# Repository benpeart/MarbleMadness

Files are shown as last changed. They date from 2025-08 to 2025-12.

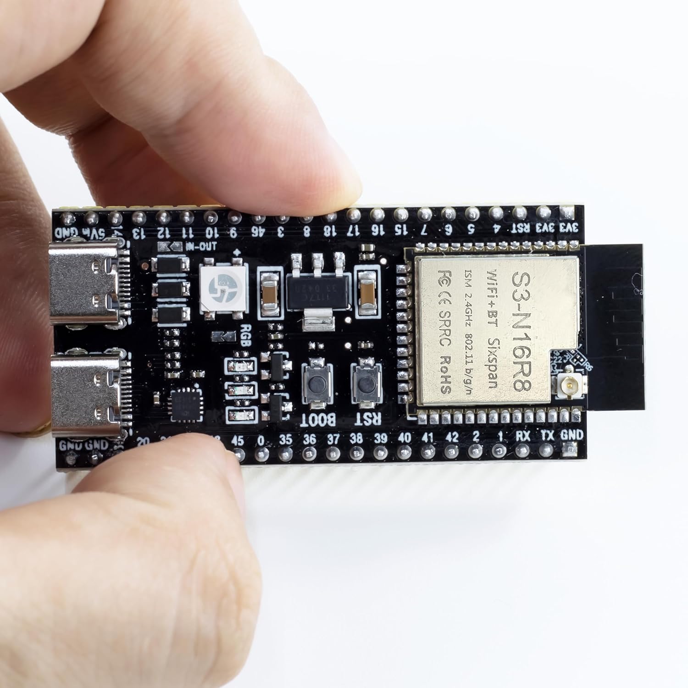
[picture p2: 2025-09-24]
documentation/81TZLf-2A1L._AC_SL1500_.jpg

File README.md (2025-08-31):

# Marble Madness
A Digital Marble Roller maker project.

## Configure WiFi settings

When Marble Madness first boots up, it will attempt to connect to WiFi using the current settings.
If that fails, it will will go into "Access Point mode" which will allow you to access it via WiFi using your laptop or phone.

Connect tothe  Marble Madness WiFi access point with your device and follow the onscreen instructions to configure the WiFi settings.
Marble Madness will then reboot and connect using the updated settings.

Any time Marble Madness cannot connect with the current WiFi settings, it will go into AP mode so that the settings can be updated.
If you are still having problems, reboot Marble Madness (unplug/plug) twice a few seconds apart (less than 10) and the settings will be cleared and it will go into AP mode.

## REST API documentation

Marble Madness connects to the WiFi with the device name "MarbleMadness." The web ui and REST API can be found at http://MarbleMadness/. 
Alternately, check your router for the IP address.

There are four REST endpoints that make up the REST API:

1. "http://MarbleMadness/api/settings"
1. "http://MarbleMadness/api/modes"
1. "http://MarbleMadness/api/faces"

## 'Settings' REST API

A GET sent to the Settings endpoint will return a result that includes the following entries:
PUT will allow you to set some or all of the same values.

```
{
    "mode": "MarbleMadness",
    "brightness": 255,
    "speed": 25,
    "clockFace": "Off",
    "clockColor": "#FFFFFF"
}
```

### Mode

The mode specifies which of the available MarbleMadness modes is currently active. This can vary as more are added or removed but currently the list of available modes includes:

```
{
    "MarbleRoller",
    "xy_test",
    "test",
    "off"
}    
```        

### Brightness

The valid range is 0 (off) to 255 (bright). The default is 255.

### Speed

Speed is a value between 0 (slow) to 255 (fast). The default is 127.
Not all modes can honor all speeds; each one is responsible for making a 'best effort.'

### clockFace

Choose what clock face (if any) is displayed.

```
{
    "Off",
    "Digital",
    "Analog"
}
```

### clockColor

A hexadecimal color is specified with: #RRGGBB, where the RR (red), GG (green) and BB (blue) hexadecimal integers specify the components of the color.

## 'Modes' REST API

A GET sent to the /api/modes endpoint will return an array of the available modes.
PUT will allow you to set some or all of the same values.

A sample result would be the following:

```
["MarbleRoller","xy_test","test"]
```

## 'Faces' REST API

A GET sent to the /api/faces endpoint will return an array of the available clock faces.
PUT will allow you to set some or all of the same values.

A sample result would be the following:

```
["Off","Digital","Analog"]
```

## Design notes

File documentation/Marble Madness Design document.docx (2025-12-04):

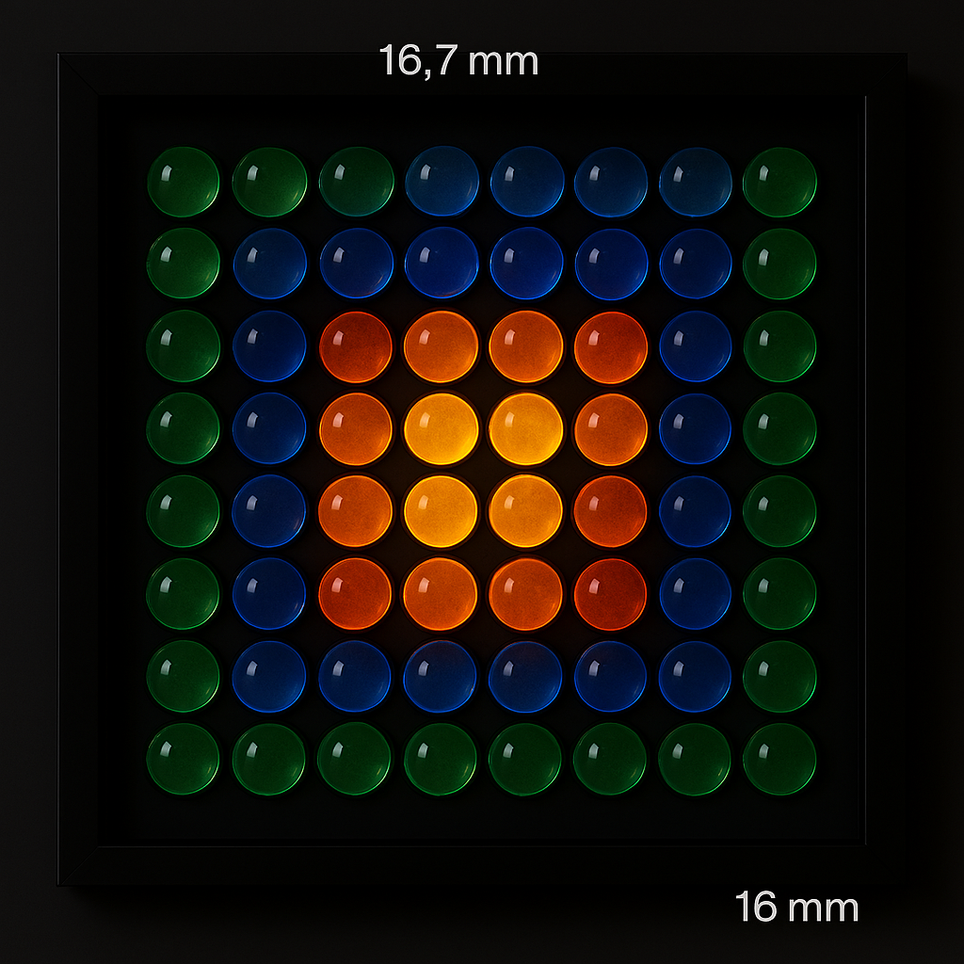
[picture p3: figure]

Here’s a clean layout plan for pairing 16 mm marbles with a 60 LEDs/m WS2812B strip (https://www.amazon.com/dp/B01CDTE9UC?th=1) (≈ 16.67 mm LED pitch) so that each marble gets its own “pixel” without crowding or gaps.

📐 Core Measurements

Element | Size / Spacing
Marble diameter | 16 mm
LED pitch (center-to-center) | 16.67 mm
Recommended hole center spacing | 16.7 mm
Recommended hole diameter | 15.8–16.0 mm

# Hardware Notes

- For reference, the kaleidoscope has 20 x 39 = 780 pixels
- A ‘standard’ marble is ~16mm in diameter
- A 60 LEDs/m WS2812B strip (https://www.amazon.com/dp/B01CDTE9UC?th=1) has a 16.67mm LED pitch
  - Dave’s 3D printer has a print volume of 350 x 350 x 325 mm or 19 x 19 = 361 marbles (leaving room for a margin and frame).

## Power

- usb c pd adjustable power supply?
- DC 4.75-23V to 3.3V Buck Converter Board (https://www.amazon.com/dp/B0B779CGJQ?ref=ppx_yo2ov_dt_b_fed_asin_title&th=1)

# Software Notes

1. Why does checking dirty flag make updates jerky (esp Matrix)
2. Fireworks
3. Googley eyes
4. Water ripple
5. Rainfall
6. Games
  a. Tetris
  b. Tron
  c. Breakout
  d. Frozen bubble game
7. Hourglass?
8. Lava lamp
9. Display static patterns/images
  a. clock that changes every minute
10. Display dynamic patterns/images
  a. Animated gifs, videos, etc
11. Animated transitions
  a. Marbles ‘fall’ from the top down in a random pattern ala connect 4 (need a physics engine (https://github.com/erincatto/box2d)?)
  b. Marbles ‘fall’ out the bottom ala Connect 4
  c. Marbles ‘roll’ down from row to row filling in the picture
    i. Try using every other row to ‘draw’ the track the marbles are rolling down
  d. Standard transitions:
    i. Simple Cut
    ii. Fade to/from black
    iii. Alpha blend to next picture
    iv. Wipe
    v. Push/slide from left/right/top/bottom - old slide out, new slide in

# Done

1. Connect 4 clock
  a. Only have enough perf to animate the marbles needed for the clock
  b. Only need vertical walls around numbers (fewer box2d items to compute)
  c. Only need 1 ‘floor’ below the bottom row of numbers in the middle of the screen
  d. Store which marbles are ‘lit’ in parallel array initialized by drawDigitalClock() in RealTimeClock.cpp
  e. When the minute changes, remove the floor and when all marbles have left the screen, replace floor then move all the marbles (with the new time) above the top of the screen so they can fall into place
2. Conway game of life
3. marble roller (simulated and physics based, with and without physical ‘tracks’)
  a. Try alpha blending between marbles in motion (ala Matrix/Kaleidoscope) to give a better sense of motion. Look at “lerp” (ask AI). Or let them dim ala ‘Matrix.’
4. ‘Ringer’ game - marbles in center, one is ‘shot’ from side, hits marbles, they scatter
5. “Bounce” where marbles drop to the bottom of the display with random direction and speed
6. “Pachinko” simulate the marbles and pins of the Pachinko game
7. “Fire” and “Matrix” – exactly what you think…

# Conway Life Pattern Information

There are excellent online libraries that collect Conway’s Game of Life patterns in RLE format, complete with descriptions and classifications.

🌐 Recommended Sites

- Life Pattern Library (life.angen.ai) A massive curated collection of over 1,700 patterns, organized into categories like oscillators, still lifes, spaceships, methuselahs, guns, and more. Each entry includes the RLE code, description, discoverer, and year life.angen.ai (https://life.angen.ai/patterns). 👉 Explore the Life Pattern Library (https://life.angen.ai/patterns)
- ConwayLife Pattern Library (conwaylife.appspot.com) Hosted by the ConwayLife community, this site provides a searchable library of RLE files, with links to LifeWiki pages for detailed explanations. You’ll find everything from simple oscillators to complex engineered spaceships conwaylife.appspot.com (https://conwaylife.appspot.com/library/). 👉 ConwayLife Pattern Library (https://conwaylife.appspot.com/library/)
- LifeWiki (conwaylife.com/wiki) The definitive encyclopedia for Game of Life. Each pattern has its own page with history, behavior, and often embedded RLE code. It’s the best place for learning the context behind patterns (e.g., why the pulsar is important, or how gliders interact).

✅ Why these are useful

- Direct RLE code → copy/paste into your engine.
- Descriptions & categories → know whether it’s a still life, oscillator, spaceship, methuselah, or seed.
- Discoverer & year → historical context for each pattern.
- Visualization tools → many sites let you run the pattern in-browser before exporting.

🔎 Quick tip for your 19×19 board

If you’re looking for contained, non-explosive patterns:

- Browse oscillators (period-2, period-3) like blinker, beacon, pulsar.
- Try small spaceships (glider, LWSS) but place them with margin.
- Avoid guns or methuselahs — they’ll eventually grow beyond 19×19.

👉 For your use case, I’d recommend starting with the Life Pattern Library at life.angen.ai/patterns — it’s cleanly organized and easy to copy RLE directly into your code.

Would you like me to pull out a short curated list of “safe” oscillators and spaceships from that library that are guaranteed to stay inside 19×19, so you don’t have to sift through hundreds of entries?

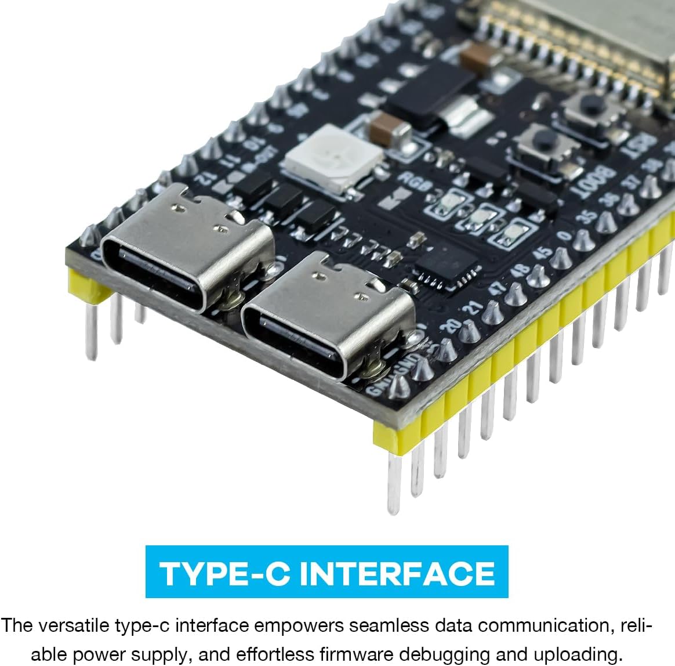
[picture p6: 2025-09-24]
documentation/61CZC+C1qqL._AC_SL1200_.jpg

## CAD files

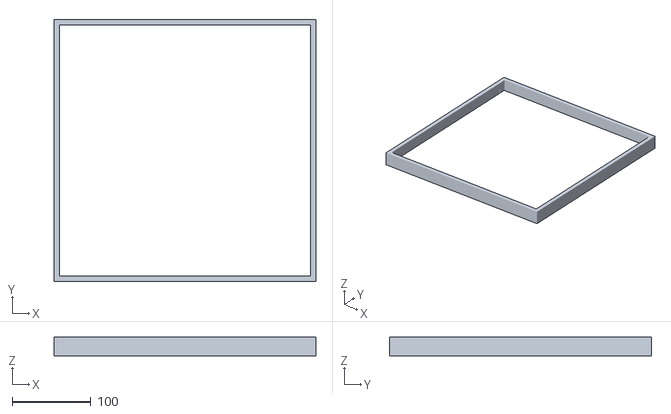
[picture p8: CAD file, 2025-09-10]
3dmodels/MarbleMadness 19x19 shadow box.stl
331.8 x 331.8 x 23.7

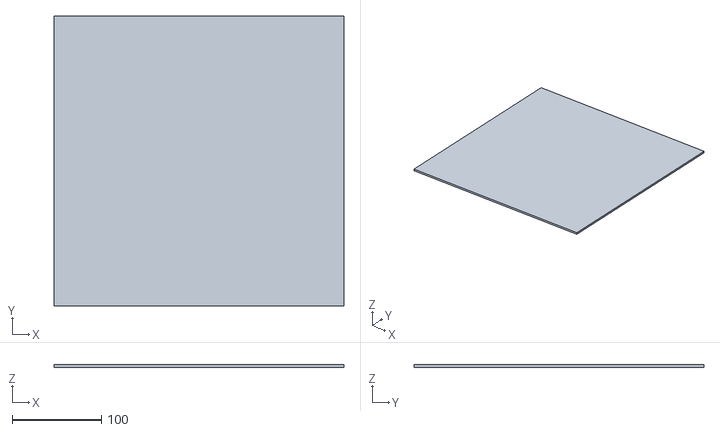
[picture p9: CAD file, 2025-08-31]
3dmodels/MarbleMadness 19x19 back plate.stl
325.8 x 325.8 x 3.00

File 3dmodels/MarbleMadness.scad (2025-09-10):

// =========================
// Marble Madness
// =========================

/* [Plate parameters] */
num_x       = 19;
num_y       = 19;
marble_d    = 16.3;      // mm diameter of largest marble (sphere)
hole_d      = 15.75;     // mm slightly smaller than the diameter of the smallest marble
pitch       = 16.67;     // mm (center-to-center)
margin      = 5;         // mm edge margin beyond outer hole edges
plate_height = 3;        // mm
led_height  = 2.15;      // mm
standoff_height = led_height + marble_d / 2; // height of standoffs
standoff_width = 0.46;   // width of standoffs
standoff_d  = 3;         // diameter of standoffs
backplate_height = 6;    // match the foam board I'm using
notch_width = 11;        // 10mm for the strip and 1mm slop
notch_height = 1;

/* [Shadow Box parameters] */
wall_thickness = 3;
lip_width = 4;
lip_height = 3;

/* [Quality settings] */
$fn_fast    = 64;        // low-poly for speed
$fn_final   = 64;        // smooth for export

// --- Auto quality based on preview mode ---
$fn_holes   = $preview ? $fn_fast : $fn_final;

module hole_plate(num_x, num_y, marble_d, hole_d, pitch, margin, plate_height, standoff_height, standoff_d) {
    // Calculate plate dimensions
    grid_span_x = (num_x - 1) * pitch;
    grid_span_y = (num_y - 1) * pitch;
    plate_x = grid_span_x + hole_d + 2 * margin;
    plate_y = grid_span_y + hole_d + 2 * margin;

    // Calculate vertical offset so sphere cuts hole_d at top face
    R = marble_d / 2;
    r = hole_d / 2;
    offset = sqrt(R*R - r*r);

    union() {
        // Plate with holes
        difference() {
            cube([plate_x, plate_y, plate_height], center = true);

            // Holes
            for (i = [0 : num_x - 1])
                for (j = [0 : num_y - 1]) {
                    x = -grid_span_x/2 + i * pitch;
                    y = -grid_span_y/2 + j * pitch;
                    // Place sphere so bottom face hole = hole_d
                    translate([x, y, plate_height/2 - offset])
                        sphere(d = marble_d, $fn = $fn_holes);
                }
        }
        
        // square louvers
        difference() {
            union() {
                y = -grid_span_y/2 - 0.5 * pitch;
                for (i = [0 : num_x]) {
                    x = -grid_span_x/2 + (i - 0.5) * pitch;
                    translate([x, 0, -standoff_height/2 - plate_height/2])
                        cube([standoff_width, plate_y - 2 * (margin - standoff_width * 1.5), standoff_height], center = true);
                    
                }

                x = -grid_span_x/2 - 0.5 * pitch;
                for (j = [0 : num_y]) {
                    y = -grid_span_y/2 + (j - 0.5) * pitch;
                    translate([0, y, -standoff_height/2 - plate_height/2])
                        cube([plate_x - 2 * (margin - standoff_width * 1.5), standoff_width, standoff_height], center = true);
                    
                }
            }

            // remove notches for the led strips
            for (j = [0 : num_y - 1]) {
                y = -grid_span_y/2 + j * pitch;
                translate([0, y, -standoff_height - plate_height/2 + notch_height/2])
                    cube([plate_x, notch_width, notch_height + 0.01], center = true);
            }

            // make notches taller to accomodate solder joints 
            for (j = [0 : num_y - 1]) {
                y = -grid_span_y/2 + j * pitch;
                translate([grid_span_x/2 + pitch/2, y, -standoff_height - plate_height/2 + notch_height/2])
                    cube([standoff_width + 0.01, notch_width, notch_height * 2 + 0.01], center = true);
                translate([-grid_span_x/2 - pitch/2, y, -standoff_height - plate_height/2 + notch_height/2])
                    cube([standoff_width + 0.01, notch_width, notch_height * 2 + 0.01], center = true);
            }
        }
/*
        // Cylinder louvers
        difference() {
            // Louvers to prevent light bleeding between cells
            for (i = [0 : num_x - 1])
                for (j = [0 : num_y - 1]) {
                    x = -grid_span_x/2 + i * pitch;
                    y = -grid_span_y/2 + j * pitch;
                    translate([x, y, -standoff_height - plate_height/2])
                        difference() {
                            cylinder(h = standoff_height, d = marble_d + wall_thickness/3, $fn = $fn_holes);
                            cylinder(h = standoff_height + 0.01, d = marble_d, $fn = $fn_holes);
                        }
                }

            // remove notches for the led strips
            for (i = [0 : num_x - 1])
                for (j = [0 : num_y - 1]) {
                    x = -grid_span_x/2 + i * pitch;
                    y = -grid_span_y/2 + j * pitch;
                    translate([x, y, -standoff_height - plate_height/2 + notch_height/2])
                        cube([plate_x, notch_width, notch_height + 0.01], center = true);
            }
        }

        // Standoffs
        for (i = [0 : num_x])
            for (j = [0 : num_y]) {
                x = -grid_span_x/2 + (i - 0.5) * pitch;
                y = -grid_span_y/2 + (j - 0.5) * pitch;
                translate([x, y, -standoff_height - plate_height/2])
                    cylinder(h = standoff_height, d = standoff_d, $fn = $fn_holes);
            }
*/        
    }
}


// =========================
// Shadow Box Module
// =========================

module shadow_box(inner_x, inner_y, height, wall_thickness, lip_width, lip_height) {
    outer_x = inner_x + 2 * wall_thickness;
    outer_y = inner_y + 2 * wall_thickness;

    difference() {
        // Outer box
        cube([outer_x, outer_y, height], center = true);

        // Inner cavity
        translate([0, 0, -lip_height])
            cube([inner_x, inner_y, height], center = true);
        
        // front lip
        translate([0, 0, height/2 - lip_height/2])
            cube([inner_x - 2 * lip_width, inner_y - 2 * lip_width, lip_height + 0.01], center = true);
    }
}

// =========================
// Modified Call with Shadow Box
// =========================

render_shadow_box = false;
render_marble_plate = true;
render_back_plate = false;

module hole_plate_with_box() {
    // Calculate plate dimensions
    grid_span_x = (num_x - 1) * pitch;
    grid_span_y = (num_y - 1) * pitch;
    plate_x = grid_span_x + hole_d + 2 * margin;
    plate_y = grid_span_y + hole_d + 2 * margin;
    
    if (render_shadow_box)
        difference() {
            // Shadow box around the marble plate
            shadow_box_height = lip_height + plate_height + standoff_height + backplate_height + plate_height / 2;
            translate([0, 0, lip_height -shadow_box_height/2 + plate_height/2])
                shadow_box(plate_x, plate_y, shadow_box_height, wall_thickness, lip_width, lip_height);
               
            // remove a notch for the LED power/data lines
            notch_width = 2;
            notch_height = plate_height + backplate_height;
            outer_x = plate_x + 2 * wall_thickness;
            grid_span_y = (num_y - 1) * pitch;
            x = -outer_x/2 + wall_thickness / 2 - 0.01;
            y = grid_span_y/2 + 0 * pitch;
            z = -(standoff_height + notch_height/2);
            translate([x - 0.01, y, z])
                cube([wall_thickness + 0.05, notch_width, notch_height + 0.01], center = true);
        }

    // Marble plate itself
    if (render_marble_plate)
        hole_plate(num_x, num_y, marble_d, hole_d, pitch, margin, plate_height, standoff_height, standoff_d);
    
    // Back plate
    if (render_back_plate)
        translate([0, 0, plate_height/2 -standoff_height -backplate_height])
            color("black") 
                cube([plate_x, plate_y, backplate_height], center = true);
}

// --- Call ---
hole_plate_with_box();

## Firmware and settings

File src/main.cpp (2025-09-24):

#include "main.h"
#include "debug.h"
#include "settings.h"
#include "modes.h"

#ifdef WIFI
#include "WiFiHelpers.h"

#ifdef REST
#include <AsyncJson.h>
#include <ArduinoJson.h>
#endif // REST

#ifdef TIME
#include "RealTimeClock.h"
#endif // TIME

#endif // WIFI

//
// GLOBAL PIN DECLARATIONS -------------------------------------------------
//
// setup our LED strips for parallel output using FastLED
#define LED_STRIP_PIN_1 18
#define LED_STRIP_PIN_2 27
#define LED_STRIP_PIN_3 26
#define LED_STRIP_PIN_4 25
#define LED_TYPE WS2812B
#define COLOR_ORDER GRB

#ifdef REST
// update the FastLED brightness
void setBrightness(int brightness)
{
  // constrain our total brightness from MIN_BRIGHTNESS to MAX_BRIGHTNESS so it doesn't get too dark
  int newBrightness = constrain(brightness, MIN_BRIGHTNESS, MAX_BRIGHTNESS);

  // adjust our brightness if it has changed
  if (newBrightness != settings.brightness)
  {
    settings.brightness = newBrightness;
    DB_PRINTF("new brightness = %d\r\n", settings.brightness);

    FastLED.setBrightness(dim8_raw(settings.brightness));
    leds_dirty = true;
  }
}

// update the speed
void setSpeed(int speed)
{
  // constrain our speed to valid range
  int newSpeed = constrain(speed, 0, MAX_SPEED);

  // adjust our speed if it has changed
  if (newSpeed != settings.speed)
  {
    settings.speed = newSpeed;
    DB_PRINTF("new speed = %d\r\n", settings.speed);
  }
}

void setRESTSettings(AsyncWebServerRequest *request, JsonVariant &json)
{
  const JsonObject &jsonObj = json.as<JsonObject>();

  DB_PRINTLN("REST setRESTSettings:");

  // update the brightness (if it was passed)
  JsonVariant brightness = jsonObj["brightness"];
  if (!brightness.isNull())
  {
    setBrightness((int)brightness);
  }

  JsonVariant speed = jsonObj["speed"];
  if (!speed.isNull())
  {
    setSpeed((int)speed);
  }

  const char *modeName = jsonObj["mode"];
  if (modeName)
  {
    setMarbleMadnessMode(modeName);
  }

#ifdef TIME
  const char *clockFace = jsonObj["clockFace"];
  if (clockFace)
  {
    setClockFace(clockFace);
  }

  JsonVariant clockColor = jsonObj["clockColor"];
  if (!clockColor.isNull())
  {
    uint32_t color;

    sscanf(clockColor, "#%06X", &color);
    setClockColor(CRGB(color));
  }
#endif // TIME

  request->send(200, "text/plain", "OK");
}

void getRESTSettings(AsyncWebServerRequest *request)
{
  JsonDocument doc;
  String response;

  doc["mode"] = getMarbleMadnessMode(settings.mode);
  doc["brightness"] = settings.brightness;
  doc["speed"] = settings.speed;
#ifdef TIME
  doc["clockFace"] = getClockFace(settings.clockFace);
  char color[8];
  sprintf(color, "#%06X", settings.clockColor.r << 16 | settings.clockColor.g << 8 | settings.clockColor.b);
  doc["clockColor"] = color;
#endif // TIME

  serializeJson(doc, response);
  DB_PRINTLN("REST getRESTSettings: " + response);
  request->send(200, "text/json", response);
}

void getModes(AsyncWebServerRequest *request)
{
  // allocate the memory for the document
  JsonDocument doc;

  // create an empty array
  JsonArray array = doc.to<JsonArray>();

  // add the names
  for (int x = 0; x < marblemadnessModes; x++)
  {
    if (getMarbleMadnessModeShowInRESTAPI(x))
      array.add(getMarbleMadnessMode(x));
  }

  // serialize the array and send the result
  String response;
  serializeJson(doc, response);
  DB_PRINTLN("REST getModes: " + response);
  request->send(200, "text/json", response);
}

#ifdef TIME
void getFaces(AsyncWebServerRequest *request)
{
  // allocate the memory for the document
  JsonDocument doc;

  // create an empty array
  JsonArray array = doc.to<JsonArray>();

  // add the names
  for (int x = 0; x < clockFaces; x++)
  {
    array.add(getClockFace(x));
  }

  // serialize the array and send the result
  String response;
  serializeJson(doc, response);
  DB_PRINTLN("REST getFaces: " + response);
  request->send(200, "text/json", response);
}
#endif // TIME
#endif // REST

//
// SETUP FUNCTION -- RUNS ONCE AT PROGRAM START ----------------------------
//

void setup()
{
#ifdef DEBUG
  // 3 second delay for recovery
  delay(3000);

  Serial.begin(115200);
  while (!Serial)
    ; // wait for serial port to connect. Needed for native USB port only
  DB_PRINTLN("\nStarting MarbleMadness on " + String(ARDUINO_BOARD));

  // debug info about the ESP32 we are running on
  DB_PRINTLN("ESP32 Chip Model: " + String(ESP.getChipModel()));
  DB_PRINTLN("ESP32 Chip Revision: " + String(ESP.getChipRevision()));
  DB_PRINTLN("ESP32 Chip Cores: " + String(ESP.getChipCores()));
  DB_PRINTLN("ESP32 CPU Frequency: " + String(ESP.getCpuFreqMHz()) + " MHz");
  DB_PRINTLN("ESP32 Flash Size: " + String(ESP.getFlashChipSize() / (1024 * 1024)) + " MB");
  DB_PRINTLN("ESP32 Flash Speed: " + String(ESP.getFlashChipSpeed() / 1000000) + " MHz");
  DB_PRINTLN("ESP32 PSRAM Size: " + String(ESP.getPsramSize())); // Should print 8388608
  DB_PRINTLN("ESP32 Free PSRAM: " + String(ESP.getFreePsram())); // Shows available heap in PSRAM
#endif

  // initialize the settings from persistent storage
  settingsSetup();

#ifdef WIFI
  // connect to wifi or enter AP mode so it can be configured
  wifi_setup();

#ifdef REST
  // setup the REST API endpoints and handlers
  webServer.on("/api/settings", HTTP_GET, getRESTSettings);
  AsyncCallbackJsonWebHandler *handler = new AsyncCallbackJsonWebHandler("/api/settings", setRESTSettings);
  webServer.addHandler(handler);
  webServer.on("/api/modes", HTTP_GET, getModes);
#ifdef TIME
  webServer.on("/api/faces", HTTP_GET, getFaces);
#endif // TIME
#endif // REST
#endif // WIFI

  // initialize the random number generator using the ESP32 hardware RNG
  randomSeed(esp_random());

  // intialize the LED strips for parallel output
  FastLED.addLeds<LED_TYPE, LED_STRIP_PIN_1, COLOR_ORDER>(leds + 0 * NUM_LEDS_PER_STRIP, NUM_LEDS_PER_STRIP).setCorrection(TypicalLEDStrip);
  FastLED.setBrightness(dim8_raw(settings.brightness));
  leds_dirty = true;

  // re-set the mode to ensure proper initialization
  int mode = settings.mode;
  settings.mode = -1; // force a change
  setMarbleMadnessMode(getMarbleMadnessMode(mode));
}

//
// LOOP FUNCTION -- RUNS OVER AND OVER FOREVER -----------------------------
//
void loop()
{
#ifdef WIFI
  // check that WiFi is still connected and reconnect if necessary
  wifi_loop();
#endif // WIFI

  // Render one frame in current mode. To control the speed of updates, use the
  // EVERY_N_MILLISECONDS(N) macro to only update the frame when it is needed.
  // Also be sure to set leds_dirty = true so that the updated frame will be displayed.
  marbleMadnessModeRender();

#ifdef TIME
  // draw the clock face (can be a null clock face - see mode_select_clock_face())
  drawClock();
#endif // TIME

  // if we have changes in the LEDs, show the updated frame
  //  if (leds_dirty)
  {
#ifdef DEBUG_SPINNER
    static const char *spinner = "|/-\\";
    static int spinner_index = 0;

    DB_PRINTF("\r%c", spinner[spinner_index]);
    spinner_index = (spinner_index + 1) % sizeof(spinner);
#endif // DEBUG_SPINNER
#ifdef DEBUG_FPS
    static unsigned long lastFPS = 0;
    static uint16_t frames = 0;
    frames++;

    // Once per second, print FPS
    EVERY_N_MILLISECONDS(1000)
    {
      Serial.print("FPS: ");
      Serial.println(frames);
      frames = 0;
    }
#endif // DEBUG_FPS

    leds_dirty = false; // clear the dirty flag before showing the frame or changes via asyncronous REST calls will fail to be drawn
    FastLED.show();
  }

  // persist any changes to the settings
  EVERY_N_SECONDS(5)
  {
    settingsPersist();
  }
}

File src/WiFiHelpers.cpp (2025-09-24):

#include "main.h"
#include "debug.h"
#ifdef WIFI
#include <WiFi.h>
#include "WiFiHelpers.h"
#ifdef ASYNC_WIFIMANAGER
#include <ESPAsyncWiFiManager.h>
#endif // ASYNC_WIFIMANAGER
#include <ESPAsyncWebServer.h>
#include <LittleFS.h>
#include "settings.h"
#include <ESPmDNS.h>
#include <ArduinoOTA.h>

#ifdef TIME
#include "RealTimeClock.h"
#endif // TIME

#ifdef DRD
// https://github.com/khoih-prog/ESP_DoubleResetDetector
#define ESP_DRD_USE_EEPROM true

// Number of seconds after reset during which a
// subseqent reset will be considered a double reset.
#define DRD_TIMEOUT 10

// RTC Memory Address for the DoubleResetDetector to use
#define DRD_ADDRESS 0

#include <ESP_DoubleResetDetector.h>

DoubleResetDetector *drd;
#endif // DRD

#define MAX_SSID_LEN 32
#define MAX_PASSWORD_LEN 64
#define MAX_HOSTNAME_LEN 32
char ssid[MAX_SSID_LEN] = "IOT";
char password[MAX_PASSWORD_LEN] = "";
char hostname[MAX_HOSTNAME_LEN] = "MarbleMadness";

// Indicates whether ESP has WiFi credentials saved from previous session, or double reset detected
bool initialConfig = false;

#define HTTP_PORT 80
AsyncWebServer webServer(HTTP_PORT);
#ifdef ASYNC_WIFIMANAGER
DNSServer dnsServer;
#endif // ASYNC_WIFIMANAGER

void wifi_setup(void)
{
    // check for a double reset where we should enter config mode
#ifdef DRD
    drd = new DoubleResetDetector(DRD_TIMEOUT, DRD_ADDRESS);
    if (drd->detectDoubleReset())
    {
        DB_PRINTLN("Double reset detected");
        initialConfig = true;
        // reset settings - for testing
        // wifiManager.resetSettings();
    }
#endif

    // connect to wifi or enter AP mode so it can be configured
    preferences.getString("hostname", hostname, sizeof(hostname));
    hostname[MAX_HOSTNAME_LEN - 1] = 0; // ensure it is null terminated
    WiFi.setHostname(hostname);

#ifdef ASYNC_WIFIMANAGER
    // Local intialization. Once its business is done, there is no need to keep it around
    AsyncWiFiManager wifiManager(&webServer, &dnsServer);

    if (initialConfig)
    {
        DB_PRINTLN(F("Starting Config Portal"));

        // initial config, disable timeout.
        wifiManager.setConfigPortalTimeout(0);
        wifiManager.startConfigPortal((String(hostname) + "AP").c_str());
    }
    else
    {
        // Give 2 minutes to configure WiFi, otherwise, just start without it
        wifiManager.setConfigPortalTimeout(120);
        wifiManager.autoConnect((String(hostname) + "AP").c_str());
    }
#else
    // Attempt to read SSID/password from preferences
    preferences.getString("wifi_ssid", ssid, sizeof(ssid));
    ssid[MAX_SSID_LEN - 1] = 0; // ensure it is null terminated
    preferences.getString("wifi_password", password, sizeof(password));
    password[MAX_PASSWORD_LEN - 1] = 0; // ensure it is null terminated

    WiFi.mode(WIFI_STA);
    WiFi.begin(ssid, password);

    unsigned long start = millis();
    while (WiFi.status() != WL_CONNECTED)
    {
        if (millis() - start >= 30000)
        {
            DB_PRINTLN(F("WiFi connect timed out"));
            return;
        }
        delay(200);
        DB_PRINT(F("."));
    }

#endif // ASYNC_WIFIMANAGER

    // report on our WiFi connection status
    if (WiFi.status() == WL_CONNECTED)
    {
        DB_PRINT(F("Connected. Local IP: "));
        DB_PRINTLN(WiFi.localIP());
    }

    // Setup for OTA updates
    ArduinoOTA.setHostname(hostname);
    ArduinoOTA
        .onStart([]()
                 {
                    String type;
                    if (ArduinoOTA.getCommand() == U_FLASH)
                    {
                        type = "sketch";
                    } else { // U_SPIFFS
                        type = "filesystem";
                        // TODO: is this needed?
                        // SPIFFS.end();
                    }
                    DB_PRINTLN("Start updating " + type); })
        .onEnd([]()
               { DB_PRINTLN("\nEnd"); })
        .onProgress([](unsigned int progress, unsigned int total)
                    { DB_PRINTF("Progress: %u%%\r", (progress / (total / 100))); })
        .onError([](ota_error_t error)
                 {
                    DB_PRINTF("Error[%u]: ", error);
                    if (error == OTA_AUTH_ERROR) DB_PRINTLN("Auth Failed");
                    else if (error == OTA_BEGIN_ERROR) DB_PRINTLN("Begin Failed");
                    else if (error == OTA_CONNECT_ERROR) DB_PRINTLN("Connect Failed");
                    else if (error == OTA_RECEIVE_ERROR) DB_PRINTLN("Receive Failed");
                    else if (error == OTA_END_ERROR) DB_PRINTLN("End Failed"); });

    ArduinoOTA.begin();
    DB_PRINTLN("Ready for OTA updates");

    // Start MDNS server
    if (MDNS.begin(hostname))
    {
        // Advertise HTTP service on port 80
        MDNS.addService("http", "tcp", 80);
        DB_PRINT("MDNS responder started, name: ");
        DB_PRINTLN(hostname);
    }
    else
    {
        DB_PRINTLN("Could not start MDNS responder");
    }

    // Setup the web UI by serving static files from LittleFS
    if (!LittleFS.begin(false))
    {
        DB_PRINTLN("LittleFS mount failed");
    }
    else
    {
        webServer.serveStatic("/", LittleFS, "/").setDefaultFile("index.html");
        DB_PRINTLN("LittleFS mount success");
    }
    webServer.onNotFound([](AsyncWebServerRequest *request)
                         { request->send(404, "text/plain", "FileNotFound"); });
#ifdef SPIFFSEDITOR
    httpServer->addHandler(new SPIFFSEditor(SPIFFS));
#endif // SPIFFSEDITOR

    webServer.begin();

#ifdef TIME
    // intialize the real time clock
    rtc_setup();
#endif
}

void wifi_loop(void)
{
#ifdef DRD
    // Call the double reset detector loop method every so often so that it can recognize when the timeout expires.
    // You can also call drd.stop() when you wish to no longer consider the next reset as a double reset.
    drd->loop();
#endif

    // check for OTA updates
    ArduinoOTA.handle();

    // if we lost WiFi, try to reconnect
    if ((WiFi.status() != WL_CONNECTED))
    {
        DB_PRINTLN(F("\nWiFi lost. Attempting to reconnect"));

#ifdef ASYNC_WIFIMANAGER
        // Local intialization. Once its business is done, there is no need to keep it around
        AsyncWiFiManager wifiManager(&webServer, &dnsServer);

        // attempt to reconnect
        wifiManager.autoConnect((String(hostname) + "AP").c_str());
#else
        WiFi.mode(WIFI_STA);
        WiFi.begin(ssid, password);
#endif // ASYNC_WIFIMANAGER

        // report on our WiFi connection status
        if (WiFi.status() == WL_CONNECTED)
        {
            DB_PRINT(F("Connected. Local IP: "));
            DB_PRINTLN(WiFi.localIP());
        }
    }
}
#endif // WIFI

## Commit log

2025-08-22 add standoffs
    [Marble Mat.scad]
2025-08-23 Increase the size of the holes in the marble mat to 16mm
    Increase the thickness of the mat to 3mm
    Remove the perimeter standoffs and replace them with more between the hole
    standoffs so the LED strips can be attached more easily.
    [Marble Mat.scad]
2025-08-23 Modify the sphere removed the marble mat that holds the marbles to be large enough to hold the largest marble but still positioned such that the hole is small enough to prevent the smallest marble fr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
    [Marble Mat.scad]
2025-08-27 Add code to:
    - initialize wifi with a WiFi configuration UI and DRD to reset settings
    - provide a web UI to view and configure (via REST APIs) settings
    - create two test modes that will light up the LEDs in sequential order and in X,Y order
    - add clock support with analog hands (the digital display will come later)
    a
    [Marble Mat.scad]
2025-08-28 get LEDs working
2025-08-29 Update Marble Mat.scad to add a shadow box and backlate.
    [Marble Mat.scad]
2025-08-29 Remove a notch from the shadow box to allow the power and data lines to pass through.
    [Marble Mat.scad]
2025-08-29 Fix XY function so that it propery maps x,y coordinates to LED index following the serpentine layout. Add several new modes.
    [Sukh 16mm Marble Sizes.xlsx]
2025-08-29 Switch from ElegantOTA to ArduinoOTA for updates Add a mDNS server so the device can be identified by name (even if your router doesn't support it)
    [WiFiHelpers.cpp]
2025-08-31 Add simple 'MarbleRoller' implementation that randomly drops a marble in the top left corner and then it 'rolls' back and forth to the bottom where it disappears. This will help test whether I can gi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
    [Marble Mat.scad, MarbleMadness 19x19 back plate.stl, MarbleMadness 19x19 shadow box.stl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]
2025-09-01 Update 3D model to include new marble mat design that removes the standoffs and adds louvers to prevent the light from bleeding between LEDs. Optimize the MarbleRoller code by doing all the logic in 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
    [MarbleMadness.scad]
2025-09-03 Write a new displaynumbers function with a 3x5 bit field defined font Update the LED brightness from the settings on initial startup Switch to a 50% blend on the clock display
2025-09-03 Fix the font for the digit '4'
    Switch from the 'getColor' function pointer method of setting LEDs to a 'setLED' function pointer so that the caller controls where the LEDs are set. We'll need this later when doing transitions that display the clock.
2025-09-03 Work around compiler bug in setClockColor. The lack of an explicit 'return' meant it continued execution into the next function (rtc_setup) Add an optional FPS output to help debug display issues
    [main.cpp]
2025-09-06 Update the Marble Madness model to have a marble mat that is thicker and made from foam board.
    [MarbleMadness.scad]
2025-09-10 Add a new bounce mode that uses a physics engine to simulate bouncing marbles and update main.cpp to properly initialize the mode on startup. This also adds the ability to have an enter and exit func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
    The physics engine should be cloned into the lib directory from https://github.com/benpeart/box2d-lite.
    This is a lightweight version of Box2D suitable for embedded systems that has
    been modified to support restitution so that objects can bounce.
    [MarbleMadness 19x19 shadow box.stl, MarbleMadness.scad]
2025-09-15 Switch from Box2D-lite to the full Box2D library for better physics simulation. I just couldn't get the lite version to behave as expected with collisions.
    The Box2D library should be cloned from https://github.com/erincatto/box2d
    into the lib/ folder. Then change B2_MAX_WORLDS to 1 in src/constants.h
2025-09-17 Add a new MarbleTrack mode draws the track and the rolls the marble down that track to make it more visibly obvious what is happening.
    Add a pachinko mode that uses the Box2D physics engine
    to create a pachinko game where marbles fall through a series of pegs.
    The Marble Madness design document has been updated to reflect these changes.
2025-09-17 Update MarbleTrack to draw the track and then have marbles move over it honoring the track positions.
2025-09-24 Switch to the ESP32 S3 Dev board N16R8 (16MB Flash, 8MB PSRAM). Add some debug spew to check the ESP32 chip, flash and PSRAM data. Remove ESPAsyncWiFiManager as it doesn't work and instead just pull 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
    [WiFiHelpers.cpp, main.cpp]
